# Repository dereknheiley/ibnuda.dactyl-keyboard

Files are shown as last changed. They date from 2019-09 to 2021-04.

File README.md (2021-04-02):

# Forked version of Generator for Dactyl & Dactyl Manuform Keyboards

This is a fork of [the ibnuba fork](https://github.com/ibnuda/dactyl-keyboard) of the [tshort fork](https://github.com/tshort/dactyl-keyboard) of the [Dactyl](https://github.com/adereth/dactyl-keyboard), a parameterized, split-hand, concave, columnar, ergonomic keyboard.

If you want to read the old ibnuba `README.md`, go [here](README.ibnuba.md).

If you want to read the old old tshort `README.md`, go [here](README.keyboard.md).

## Goals
1. Improve strength of kailh hotswap holder
2. Add Support for glueing LED strips to provide per-key LED RGB backlighting
3. Tweak row, and column curvatures for smaller hands.

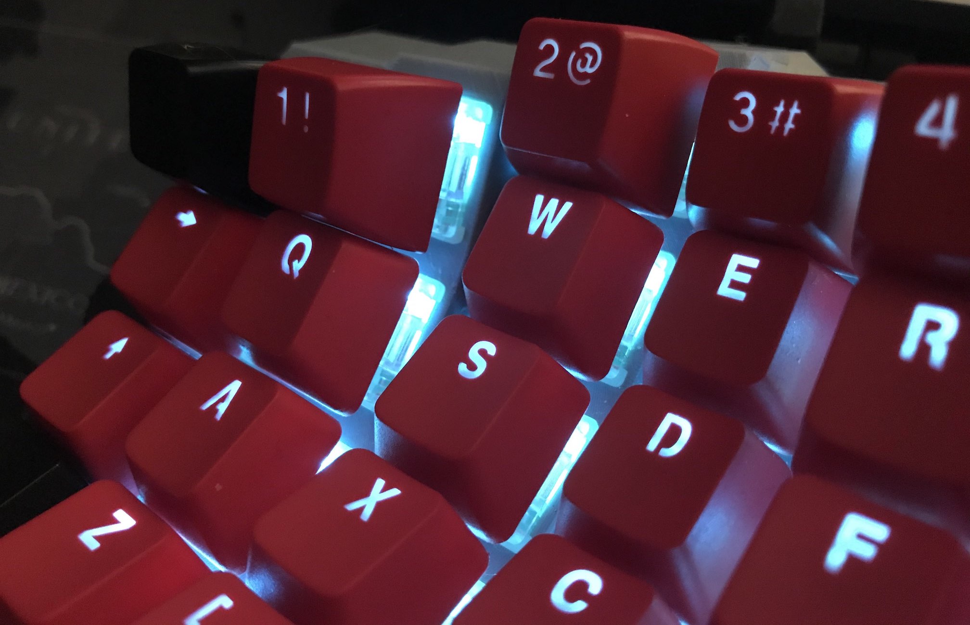
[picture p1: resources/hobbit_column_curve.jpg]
Column Curvature


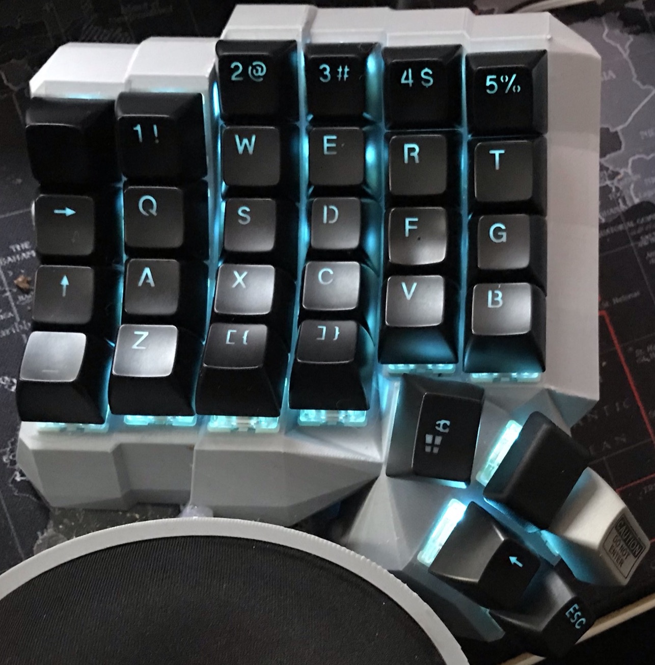
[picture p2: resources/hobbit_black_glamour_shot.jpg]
Black Keycap Glamour Shot

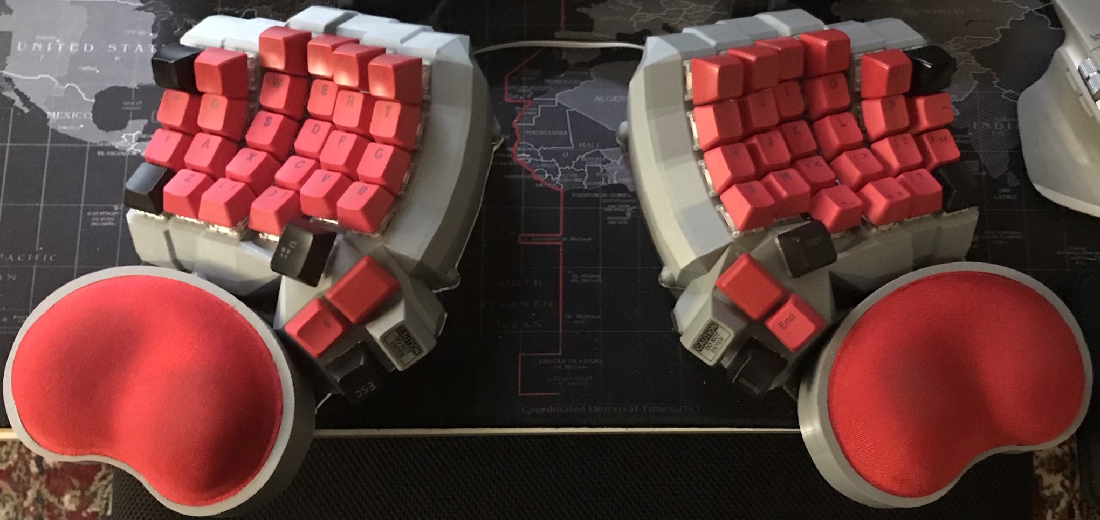
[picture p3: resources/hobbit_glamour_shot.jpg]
Glamour Shot


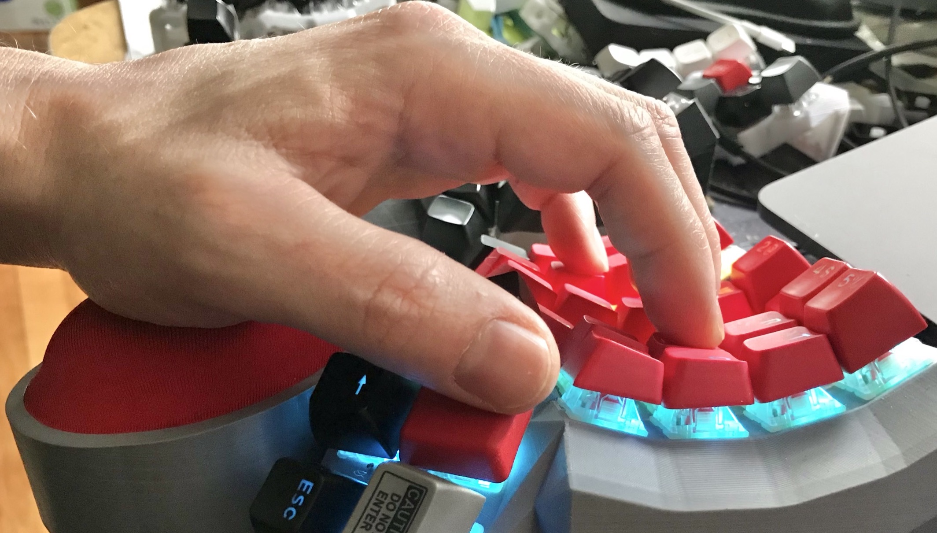
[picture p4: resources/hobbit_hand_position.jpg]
Hand Position


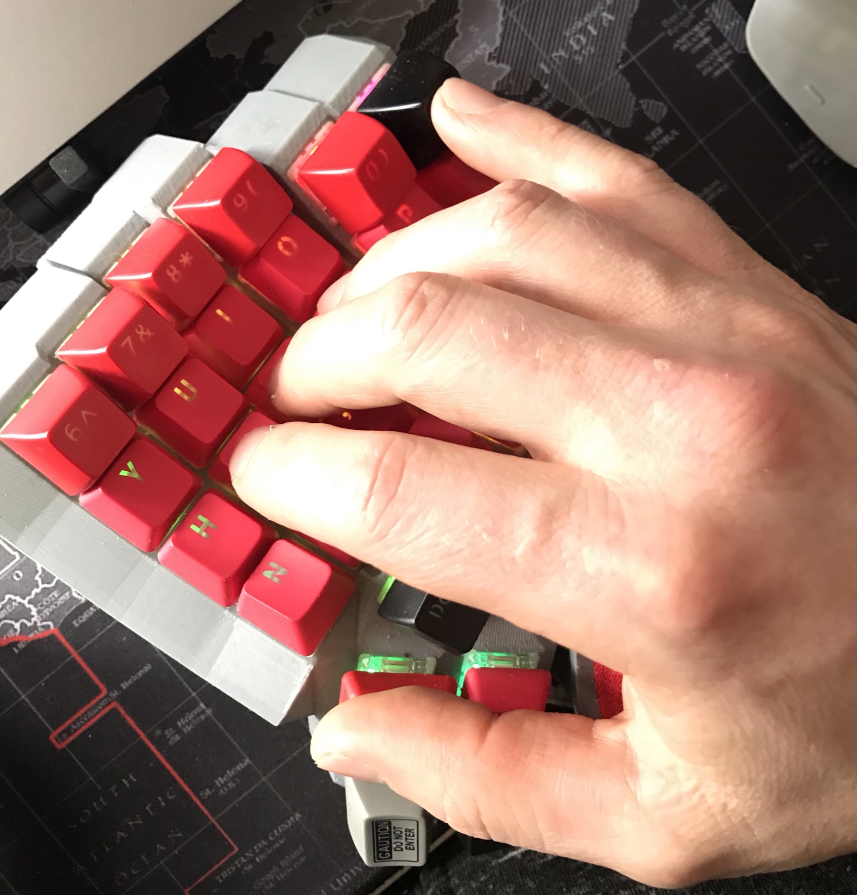
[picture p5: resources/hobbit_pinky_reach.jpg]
Pinky Reach


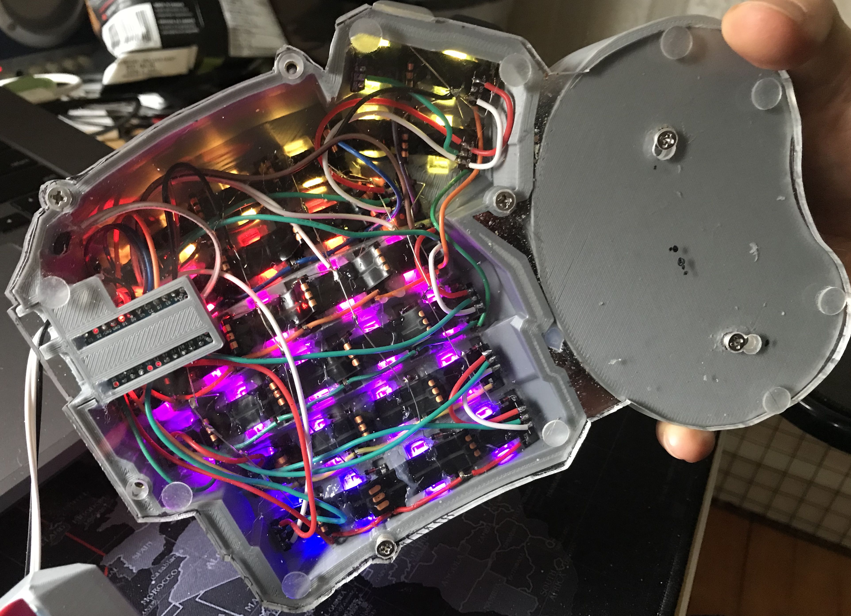
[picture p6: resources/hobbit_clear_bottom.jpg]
Clear Bottom


# Generate OpenSCAD and STL models

## OLD
* Run `lein repl`
* In the repl run `(load-file "src/dactyl_keyboard/common.clj") (load-file "src/dactyl_keyboard/manuform.clj")`
* This will regenerate the `things/*.scad` files
* Use OpenSCAD to open a `.scad` file.
* Make changes to design, repeat `load-file`, OpenSCAD will watch for changes and rerender.
* When done, use OpenSCAD to render, then export model STL files which can be printed by 3d printer slicing software.

## NEW (faster)
* Run `lein auto generate`
* This will regenerate the `things/*.scad` files whenever the .clr file is saved
* Use OpenSCAD to open a `.scad` file.
* Make changes to design in `src/dactyl_keyboard/dactyl.clj`, open scad files will auto regenerate, OpenSCAD will rerender.
* When done, use OpenSCAD to render, then export model STL files which can be printed by 3d printer slicing software.

## Batch (parallel) Processing
* Edit the path for OpenSCAD in `create-models.sh` if needed
* Change any other settings for which files you want to render
* Wait for STL files to appear (this may take a minute or two) 

## License
Copyright © 2015-2020 Matthew Adereth, Tom Short, Ibnu D. Aji, Derek Nheiley et. al.

The source code for generating the models (everything excluding the [things/](things/) and [resources/](resources/) directories is distributed under the [GNU AFFERO GENERAL PUBLIC LICENSE Version 3](LICENSE).  The generated models and PCB designs are distributed under the [Creative Commons Attribution-NonCommercial-ShareAlike License Version 3.0](LICENSE-models).

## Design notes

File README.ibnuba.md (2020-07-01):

# Web Generator for Dactyl Keyboard

If you want to read the old `README.md`, go [here](README.keyboard.md).

## Development

To tinker around this thing, follow these steps:

1. Install JDK and [leiningen](https://leiningen.org/#install).
2. Change directory to this repository.
3. Run `lein ring server-headless`.
4. Change something in `src/dactyl_keyboard/handler.clj`.
5. Open [localhost:3030](http://localhost:3030).

## Deployment

To deploy it in a computer, follow these steps:

1. Install JDK and [leiningen](https://leiningen.org/#install).
2. Change directory to this repository.
3. Run `lein ring uberjar`.
4. Copy `target/dactyl-keyboard-version-SNAPSHOT-standalone.jar` to your server.
5. In the webserver, run `java -jar dactyl-keyboard-version-SNAPSHOT-standalone.jar`.

## Old Workflow

To use old workflow where `change code -> save -> openscad reloads model`,
uncomment `(spit "things/right.scad" (write-scad (model-right c)))` in
`src/dactyl_keyboard/dactyl.clj` or `src/dactyl_keyboard/lightcycle.clj`.

## Single Key PCB

If you want to use single key PCB, please use [single pcb](https://github.com/ibnuda/single).

## License

Copyright © 2015-2020 Matthew Adereth, Tom Short, Ibnu D. Aji, et. al.

The source code for generating the models (everything excluding the [things/](things/) and [resources/](resources/) directories is distributed under the [GNU AFFERO GENERAL PUBLIC LICENSE Version 3](LICENSE).  The generated models and PCB designs are distributed under the [Creative Commons Attribution-NonCommercial-ShareAlike License Version 3.0](LICENSE-models).

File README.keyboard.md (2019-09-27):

# The Dactyl-ManuForm Keyboard
This is a fork of the [Dactyl](https://github.com/adereth/dactyl-keyboard), a parameterized, split-hand, concave, columnar, ergonomic keyboard.

Imgur

The main change is that the thumb cluster was adapted from the [ManuForm keyboard](https://github.com/jeffgran/ManuForm) ([geekhack](https://geekhack.org/index.php?topic=46015.0)). The walls were changed to just drop to the floor. The keyboard is paramaterized to allow adjusting the following: 

* Rows: 4 - 6 
* Columns: 5 and up
* Row curvature
* Column curvature
* Row tilt (tenting)
* Column tilt
* Column offsets
* Height
* Side nubs: some MX style switches don't need them.
* Wire posts: if you use amoeba pcb, it will only hinder you.
* TRRS option: instead of RJ9, you can use TRRS cables. Really fitting for weebs and ricers.
* [Rental Car](https://imgur.com/gallery/jxzEABw): to make the rows lined up.
* Promicro holes: instead of vertical hole, use the horisontal one.
* [Ergodox Style](https://geekhack.org/index.php?action=dlattach;topic=88576.0;attach=199354;image) By [Loligagger](https://geekhack.org/index.php?action=profile;u=12372):
    * Uses the last row.
    * Uses inner column.
    * Uses wide outer-pinky keys.
* [Minidox](https://www.thingiverse.com/thing:3866436): 36 keys by @ibnuda

I built a 4x5 version (40% size) for myself. The default has a bit more tenting than the Dactyl. See the following model files for configurations that may be most common:

* [40% size, (4x5)](https://github.com/tshort/dactyl-keyboard/blob/master/things/right-4x5.stl)
* [60% size, (5x6)](https://github.com/tshort/dactyl-keyboard/blob/master/things/right-5x6.stl)

## Assembly

### Generating a Design

**Setting up the Clojure environment**
* [Install the Clojure runtime](https://clojure.org)
* [Install the Leiningen project manager](http://leiningen.org/)
* [Install OpenSCAD](http://www.openscad.org/)

**Generating the design**
* Run `lein repl`
* Load the file `(load-file "src/dactyl_keyboard/dactyl.clj")`
* This will regenerate the `things/*.scad` files
* Use OpenSCAD to open a `.scad` file.
* Make changes to design, repeat `load-file`, OpenSCAD will watch for changes and rerender.
* When done, use OpenSCAD to export STL files

**Tips**
* [Some other ways to evaluate the clojure design file](http://stackoverflow.com/a/28213489)
* [Example designing with clojure](http://adereth.github.io/blog/2014/04/09/3d-printing-with-clojure/)

### Printing
Pregenerated STL files are available in the [things/](things/) directory. 
When a model is generated, it also generates a `.scad` model for a bottom plate. 
This can be exported to a DXF file in OpenSCAD.
The [things/](things/) directory also has DXF files for the bottom plate.
When laser cut, some of the inside cuts will need to be removed. 

This model can be tricky to print. 
It's wide, so I've had problems with PLA on a Makerbot with edges warping. 
This can cause the printer to think its head is jammed. 
Even if it successfully prints, warping can cause problems. 
On one print, the RJ-9 holder was squished, so I had to cut down my connector to fit.

If printed at Shapeways or other professional shops, I would not expect such problems. 

### Thingiverse

[The 4x5 STL left/right pair](https://www.thingiverse.com/thing:2349390) from the [things/](things/) directory is in the thingiverse for public printing

### Wiring

Here are materials I used for wiring.

* Two Arduino Pro Micros
* [Heat-set inserts](https://www.mcmaster.com/#94180a331/=16yfrx1)
* [M3 wafer-head screws, 5mm](http://www.metricscrews.us/index.php?main_page=product_info&cPath=155_185&products_id=455)
* [Copper tape](https://www.amazon.com/gp/product/B009KB86BU)
* [#32 magnet wire](https://www.amazon.com/gp/product/B00LV909HI)
* [#30 wire](https://www.amazon.com/gp/product/B00GWFECWO)
* [3-mm cast acrylic](http://www.mcmaster.com/#acrylic/=144mfom)
* [Veroboard stripboard](https://www.amazon.com/gp/product/B008CPVMMU)
* [1N4148 diodes](https://www.amazon.com/gp/product/B00LQPY0Y0)
* [Female RJ-9 connectors](https://www.amazon.com/gp/product/B01HU7BVDU/)

I wired one half using the traditional approach of using the legs of a diode to form the row connections. 
(I'm not great at soldering, so this was challenging for me.)
For this side, I used magnet wire to wire columns. That worked okay. 
The magnet wire is small enough, it wants to move around, and it's hard to tell if you have a good connection.

Imgur

For another half, I used stripboard for the row connections. 
This allowed me to presolder all of the diodes. 
Then, I hot-glued this in place and finished the soldering of the other diode ends. 
I like this approach quite a lot. 
Connections for the diodes were much easier with one end fixed down. 
On this half, I also used copper tape to connect columns. 
This worked a bit better than the magnet wire for me. 
For a future version, I may try just bare tinned copper wire for columns (something like #20). 
With the stripboard, it's pretty easy keeping row and column connections separate.

Imgur

Note that a telephone handset cable has leads that are reversed, so take this into account when connecting these leads to the controller.

The 3D printed part is the main keyboard. 
You can attach a bottom plate with screws. 
The case has holes for heat-set inserts designed to hold 3- to 6-mm long M3 screws. 
Then, I used wafer-head screws to connect a bottom plate. 
If wires aren't dangling, a bottom plate may not be needed. 
You need something on the bottom to keep the keyboard from sliding around. 
Without a plate, you could use a rubber pad, or you could dip the bottom of the keyboard in PlastiDip.

For more photos of the first complete wiring of v0.4, see [Imgur](http://imgur.com/a/v9eIO).

This is how the rows/columns wire to the keys and the ProMicro
Wire Diagram

#### Alternative row-driven wiring diagram for ProMicro:

NOTE: you also make sure the firmware is set up correctly (ex: change row pins with col pins)

Left Wire Diagram

Left Wire Diagram

### Firmware

Firmware goes hand in hand with how you wire the circuit. 
I adapted the QMK firmware [here](https://github.com/tshort/qmk_firmware/tree/master/keyboards/dactyl-manuform). 
This allows each side to work separately or together. 
This site also shows connections for the Arduino Pro Micro controllers.

## License

Copyright © 2015-2017 Matthew Adereth and Tom Short

The source code for generating the models (everything excluding the [things/](things/) and [resources/](resources/) directories is distributed under the [GNU AFFERO GENERAL PUBLIC LICENSE Version 3](LICENSE).  The generated models and PCB designs are distributed under the [Creative Commons Attribution-NonCommercial-ShareAlike License Version 3.0](LICENSE-models).

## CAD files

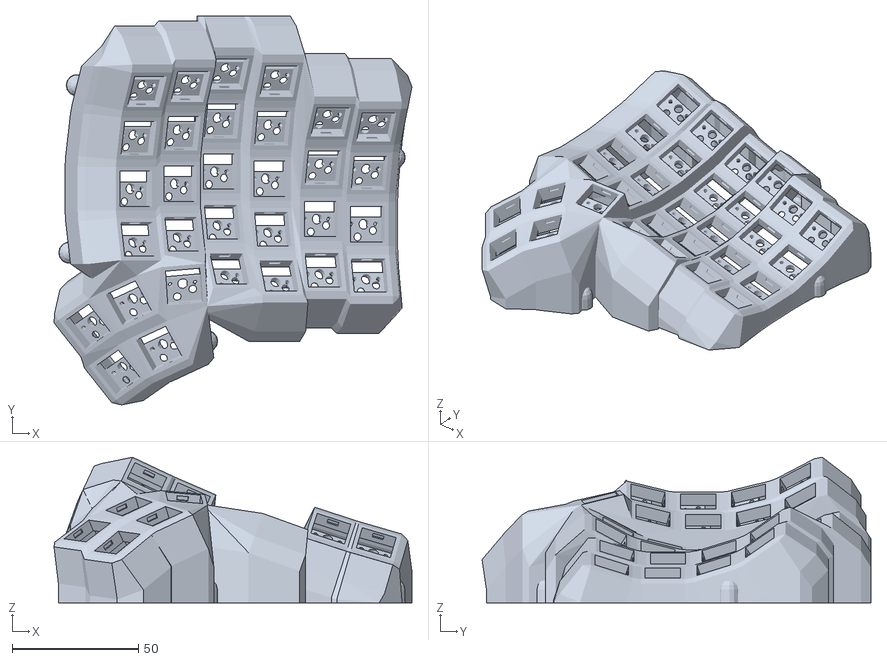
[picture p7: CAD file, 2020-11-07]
things/hobbit5x6-tight-flat-right.stl
141.7 x 154.0 x 57.6

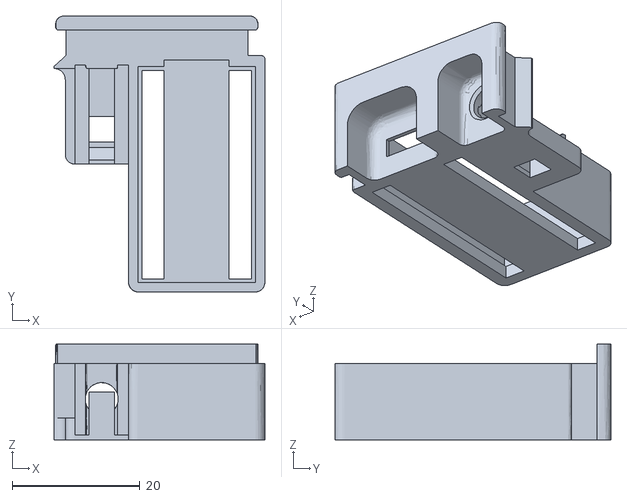
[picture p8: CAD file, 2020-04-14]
resources/public/loligagger-external-holder-promicro-v2.stl
33.0 x 43.2 x 15.0

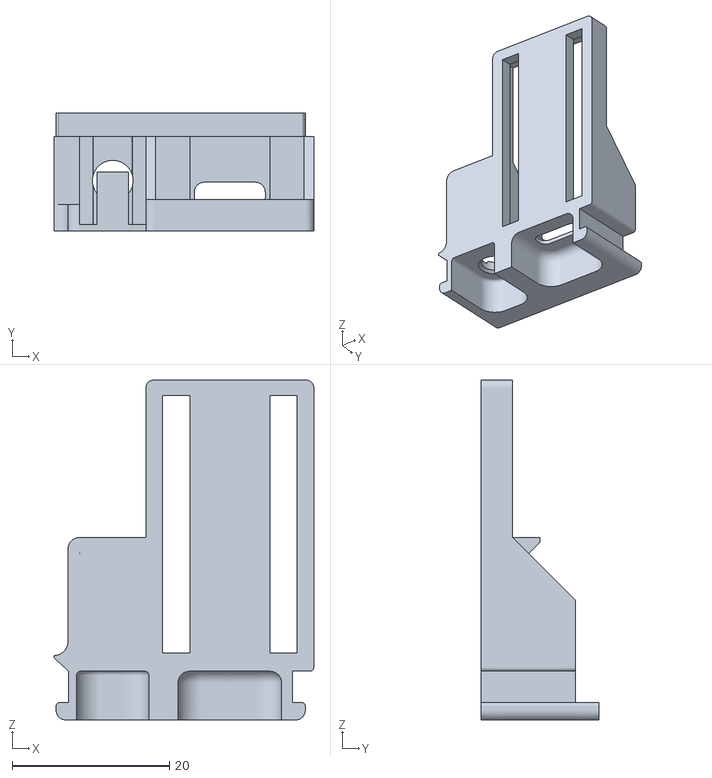
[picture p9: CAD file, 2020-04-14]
resources/public/loligagger-external-holder-elite-c-v1.stl
33.0 x 15.0 x 43.2

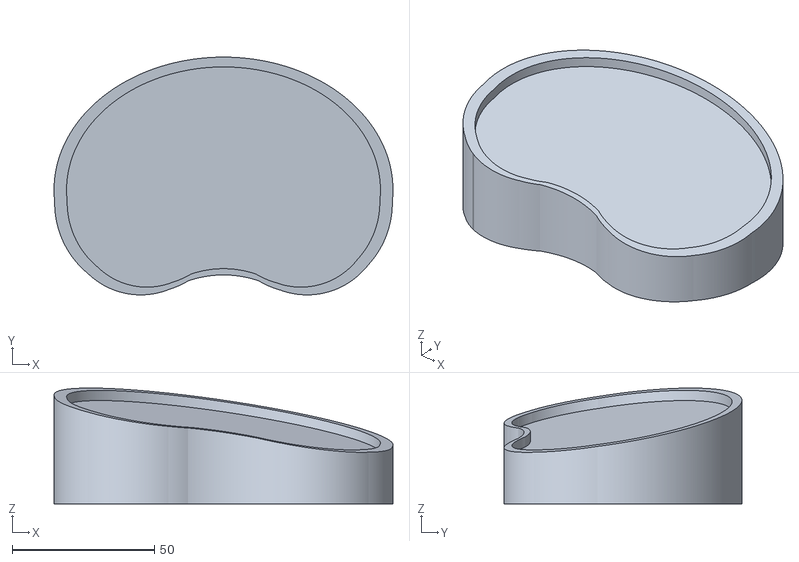
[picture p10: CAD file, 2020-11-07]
things/wrist-rest-right.stl
119.3 x 83.7 x 40.8

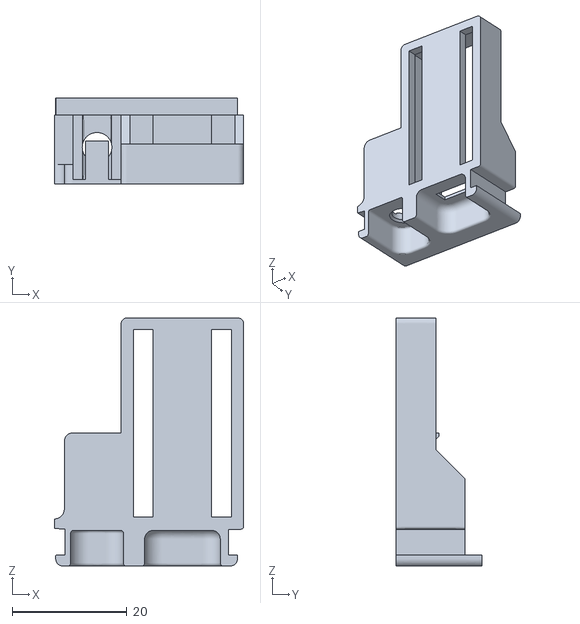
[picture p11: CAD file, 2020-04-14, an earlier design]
resources/public/loligagger-external-holder-promicro-v1.stl
33.0 x 15.0 x 43.2

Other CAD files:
things/hobbit5x6-tight-flat-left.stl
things/wrist-rest-left.stl

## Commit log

2019-07-10 added option to use trrs hole instead of rj9
2019-07-10 added option to use promicro holder instead of teensy.
2019-09-24 forgotten to fix the screw inset location.
2019-09-27 fixed some stuff.
    - there was a misplaced closing parentheses that resulted a huge block.
    - there was a wrong location in the thumb connectors.
    - added a function's doc.
    - formatting.
2019-09-27 - added stl files because why not. - updated readme. to explain the addition.
    [ergodox-left.stl, ergodox-right.stl, minidox-left.stl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]
2019-10-21 updated thumb location.
    [minidox-left.stl, minidox-right.stl]
2020-04-03 add option to generate screw inserts
2020-04-04 - removed request to google. - added generate plate button and its supporting logic.
2020-04-04 alps switch.
2020-04-09 - moved common parts to `common.clj`. - prep. for screw-inserts.
2020-04-13 Removed unnecessary files
    [ergodox-left.stl, ergodox-right.stl, left-4x5.stl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]
2020-04-13 Added external holder STL files
    [External holder (Elite-C) v1.stl, External holder (Pro Micro) v1.stl, External holder (Pro Micro) v2.stl]
2020-04-14 - exposed loligagger's stl files. - fixed plate generation for manuform. - plate generation for light cycle. - fixed functions in util.clj. i couldn't get it working on my pc.
    [loligagger-external-holder-elite-c-v1.stl, loligagger-external-holder-promicro-v1.stl, loligagger-external-holder-promicro-v2.stl]
2020-04-15 six thumb buttons.
2020-04-16 - screws for lightcycle. - refaktor (lol) some of the functions.
2020-04-16 Fix screw inserts placement
2020-04-16 Fix screw holes problem when selecting external holder
2020-04-18 Fixed problem related to the plates being incomplete
2020-05-01 plate for dm. request by u/omnisairen.
2020-05-24 calva format and 7mm web thickness for pcb.
2020-05-24 Note about single key pcb.
2020-06-02 make the thumb wall to be "obese" so the plate can fit.
2020-06-05 added 0.5mm width and height for each web around the keyholes to accomodate single pcb.
2020-06-07 - added a buildlog in examples. - updated json help to reflect the updated options. - added 8 thumb keys for the lightcycle. - added 0.5mm for external holder.
2020-06-23 3mm for lightcycle's wall thickness is too thick.
2020-06-26 plate should be ok-ish.
2020-06-28 openscad no longer crashes when opening manuform's plate.
2020-07-11 moved connector locs. one column to the center.
2020-07-26 improve clearances for pcb mount holes on hot-swap holder
2020-07-26 make hot swap holder full width of recessed switch plate holder
2020-07-26 make hot swap holder touch full y height of recessed switch plate hole for better 3d printing
2020-07-26 add support for parametric north vs south facing hailh hot swap socket holders
2020-07-27 add kailh and mx compatible teeth indent to keep switch in place when using hot swap
2020-07-28 adjust z offset of switch teeth cutout to prevent switch from lifting before contacting cutout when pulling up on switch
2020-07-28 refactor hot swap logic out to own def, tweak switch teeth cutout, fix bug with hotswap holder being backwards on left half, increase web thickness to match hotswap thickness for cleaner prints
2020-07-29 derive holder x from mount-width
2020-08-12 add options for flatter rows to prevent keycaps in 6x6 layouts with lots of column curvature from touching the case
2020-11-07 update DN hotswap holder to have LED holder option
2020-11-07 start screwing around with lightcycle to remove walls cleanly
2020-11-07 add wrist rest STLs
    [wrist-rest-left.stl, wrist-rest-right.stl]
2020-11-07 add V1 of the hobbit dactyl manuform with flat rows and tight key spacing (thinner OEM caps only)
    [hobbit5x6-tight-flat-left.stl, hobbit5x6-tight-flat-right.stl]
2020-12-13 make external holder cut through thicker cases
